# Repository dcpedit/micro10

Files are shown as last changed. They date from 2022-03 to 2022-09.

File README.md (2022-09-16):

# µ10 Keyboard

µ10_keyboard

Here you will find all the source files I used to build my µ10 (aka Micro10) keyboard.  Below is a list of features:

* 10u wide QAZ-ish layout
* Supports a 10u spacebar
* Designed to be wireless (via nice!nano + ZMK)
* Optional daughterboard for OLED and rotary encoder
* PCB uses Kailh hot swap sockets
* PCB supports a 1.25u modifier on each end if a split spacebar (2.25u + 2.75u) setup or 6.25u spacebar is utilized.  This will require modifications to the case design (mainly to add blockers).

[Keyboard Layout Editor (KLE)](http://www.keyboard-layout-editor.com/#/gists/2a9c0bfd3bc5586766325f682a7adc31)

keymap_legend
keymap_current

# ZMK Firmware

See my fork of ZMK under the `dcpedit` branch:
https://github.com/dcpedit/zmk/tree/dcpedit

The relevant files are in the `micro10` folder under shields:
https://github.com/dcpedit/zmk/tree/dcpedit/app/boards/shields/micro10

```
git clone -b dcpedit https://github.com/dcpedit/zmk.git
```

## Build
Follow the [ZMK environment setup](https://zmk.dev/docs/development/setup).  I highly recommend using VS Code & Docker.
```
cd app
west build -b nice_nano_v2 -- -DSHIELD=micro10
```
Binary will be located here.  Copy it into your nice!nano:
```
app/build/zephyr/zmk.uf2
```

# Image Gallery
https://imgur.com/a/AuKd2NT

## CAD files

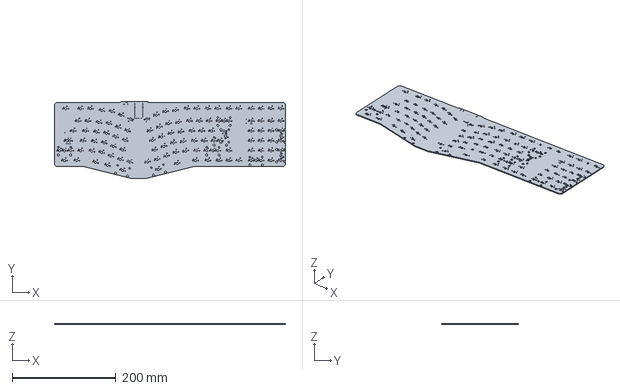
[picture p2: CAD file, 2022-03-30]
pcb/micro10.step
445.0 x 148.2 x 1.60 mm

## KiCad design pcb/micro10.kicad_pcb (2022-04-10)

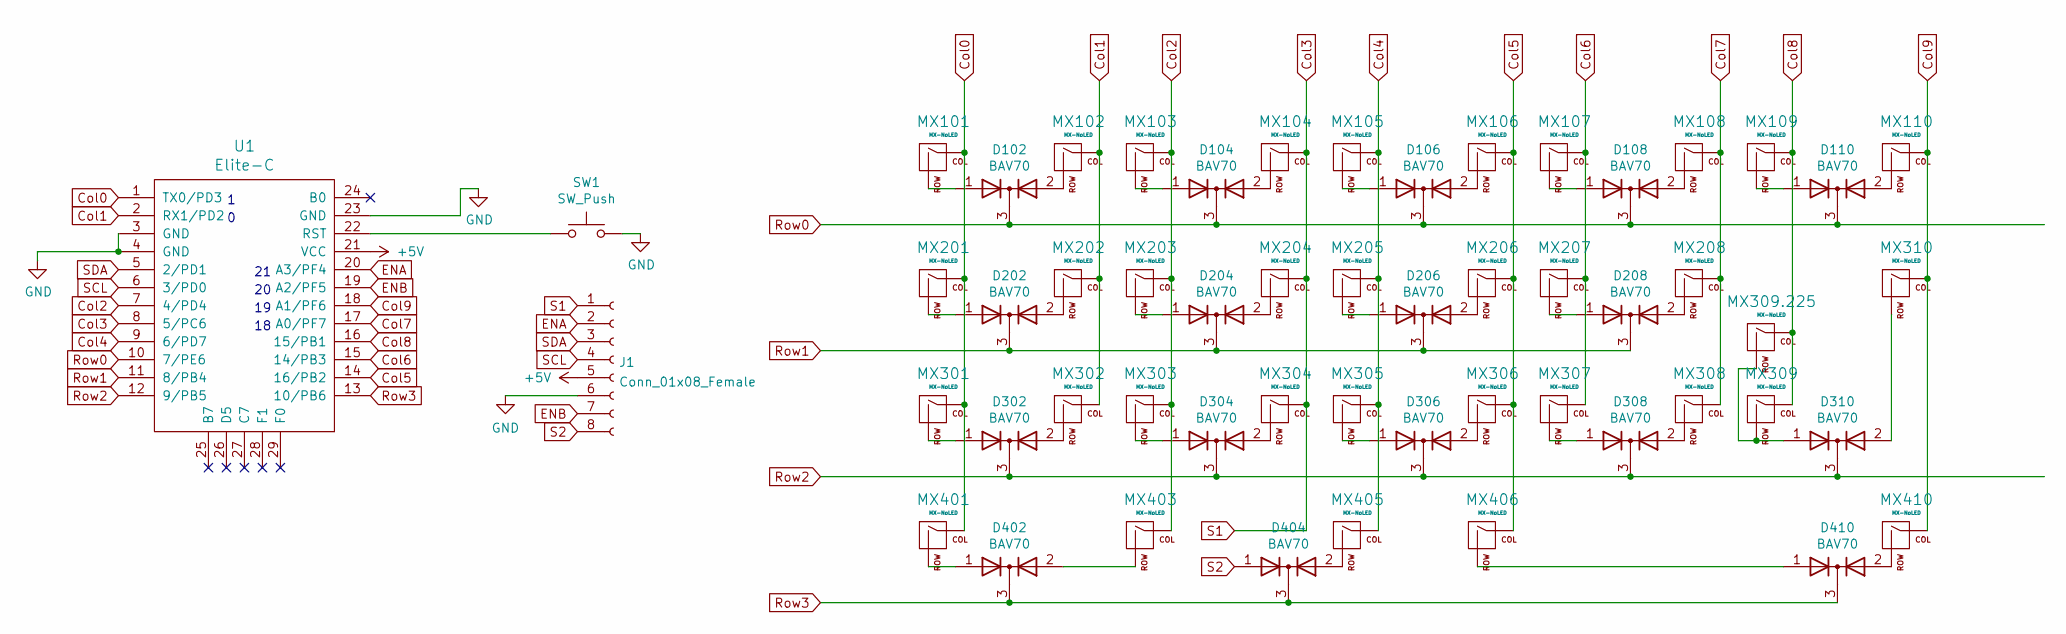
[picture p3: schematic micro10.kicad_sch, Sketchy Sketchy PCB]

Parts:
D102, D104, D106, D108, D110, D202, D204, D206, D208, D302, D304, D306, D308, D310, D402, D404, D410: BAV70; SOT-23_Handsoldering
J1: Conn_01x08_Female
MX101, MX102, MX103, MX104, MX105, MX106, MX107, MX108, MX109, MX110, MX202, MX203, MX204, MX205, MX206, MX207, MX208, MX302, MX303, MX304, MX305, MX306, MX307, MX308, MX309, MX309.225, MX310, MX403, MX405, MX406, MX410: MX-NoLED; MXOnly-1U-Hotswap
MX201: MX-NoLED; MXOnly-1.5U-Hotswap
MX301: MX-NoLED; MXOnly-1.75U-Hotswap
MX401: MX-NoLED; MXOnly-2.25U-Hotswap
SW1: SW_Push; SW_Tactile_SPST_Angled_MJTP1117
U1: Elite-C

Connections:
+5V: J1.5, U1.21 (VCC)
Col0: MX101.1 (COL), MX201.1 (COL), MX301.1 (COL), MX401.1 (COL), U1.1 (TX0/PD3)
Col1: MX102.1 (COL), MX202.1 (COL), MX302.1 (COL), U1.2 (RX1/PD2)
Col2: MX103.1 (COL), MX203.1 (COL), MX303.1 (COL), MX403.1 (COL), U1.7 (4/PD4)
Col3: J1.1, MX104.1 (COL), MX204.1 (COL), MX304.1 (COL), U1.8 (5/PC6)
Col4: MX105.1 (COL), MX205.1 (COL), MX305.1 (COL), MX405.1 (COL), U1.9 (6/PD7)
Col5: MX106.1 (COL), MX206.1 (COL), MX306.1 (COL), MX406.1 (COL), U1.14 (16/PB2)
Col6: MX107.1 (COL), MX207.1 (COL), MX307.1 (COL), U1.15 (14/PB3)
Col7: MX108.1 (COL), MX208.1 (COL), MX308.1 (COL), U1.17 (A0/PF7)
Col8: MX109.1 (COL), MX309.1 (COL), MX309.225.1 (COL), U1.16 (15/PB1)
Col9: MX110.1 (COL), MX310.1 (COL), MX410.1 (COL), U1.18 (A1/PF6)
ENA: J1.2, U1.20 (A3/PF4)
ENB: J1.7, U1.19 (A2/PF5)
GND: J1.6, SW1.2, U1.3 (GND), U1.4 (GND), U1.23 (GND)
unnamed: D102.1 (A), MX101.2 (ROW)
unnamed: D102.2 (A), MX102.2 (ROW)
unnamed: D104.1 (A), MX103.2 (ROW)
unnamed: D104.2 (A), MX104.2 (ROW)
unnamed: D106.1 (A), MX105.2 (ROW)
unnamed: D106.2 (A), MX106.2 (ROW)
unnamed: D108.1 (A), MX107.2 (ROW)
unnamed: D108.2 (A), MX108.2 (ROW)
unnamed: D110.1 (A), MX109.2 (ROW)
unnamed: D110.2 (A), MX110.2 (ROW)
unnamed: D202.1 (A), MX201.2 (ROW)
unnamed: D202.2 (A), MX202.2 (ROW)
unnamed: D204.1 (A), MX203.2 (ROW)
unnamed: D204.2 (A), MX204.2 (ROW)
unnamed: D206.1 (A), MX205.2 (ROW)
unnamed: D206.2 (A), MX206.2 (ROW)
unnamed: D208.1 (A), MX207.2 (ROW)
unnamed: D208.2 (A), MX208.2 (ROW)
unnamed: D302.1 (A), MX301.2 (ROW)
unnamed: D302.2 (A), MX302.2 (ROW)
unnamed: D304.1 (A), MX303.2 (ROW)
unnamed: D304.2 (A), MX304.2 (ROW)
unnamed: D306.1 (A), MX305.2 (ROW)
unnamed: D306.2 (A), MX306.2 (ROW)
unnamed: D308.1 (A), MX307.2 (ROW)
unnamed: D308.2 (A), MX308.2 (ROW)
unnamed: D310.1 (A), MX309.2 (ROW), MX309.225.2 (ROW)
unnamed: D310.2 (A), MX310.2 (ROW)
unnamed: D402.1 (A), MX401.2 (ROW)
unnamed: D402.2 (A), MX403.2 (ROW)
unnamed: D404.2 (A), MX405.2 (ROW)
unnamed: D410.1 (A), MX406.2 (ROW)
unnamed: D410.2 (A), MX410.2 (ROW)
unnamed: SW1.1, U1.22 (RST)
Row0: D102.3 (K), D104.3 (K), D106.3 (K), D108.3 (K), D110.3 (K), U1.10 (7/PE6)
Row1: D202.3 (K), D204.3 (K), D206.3 (K), D208.3 (K), U1.11 (8/PB4)
Row2: D302.3 (K), D304.3 (K), D306.3 (K), D308.3 (K), D310.3 (K), U1.12 (9/PB5)
Row3: D402.3 (K), D404.3 (K), D410.3 (K), U1.13 (10/PB6)
S2: D404.1 (A), J1.8
SCL: J1.4, U1.6 (3/PD0)
SDA: J1.3, U1.5 (2/PD1)

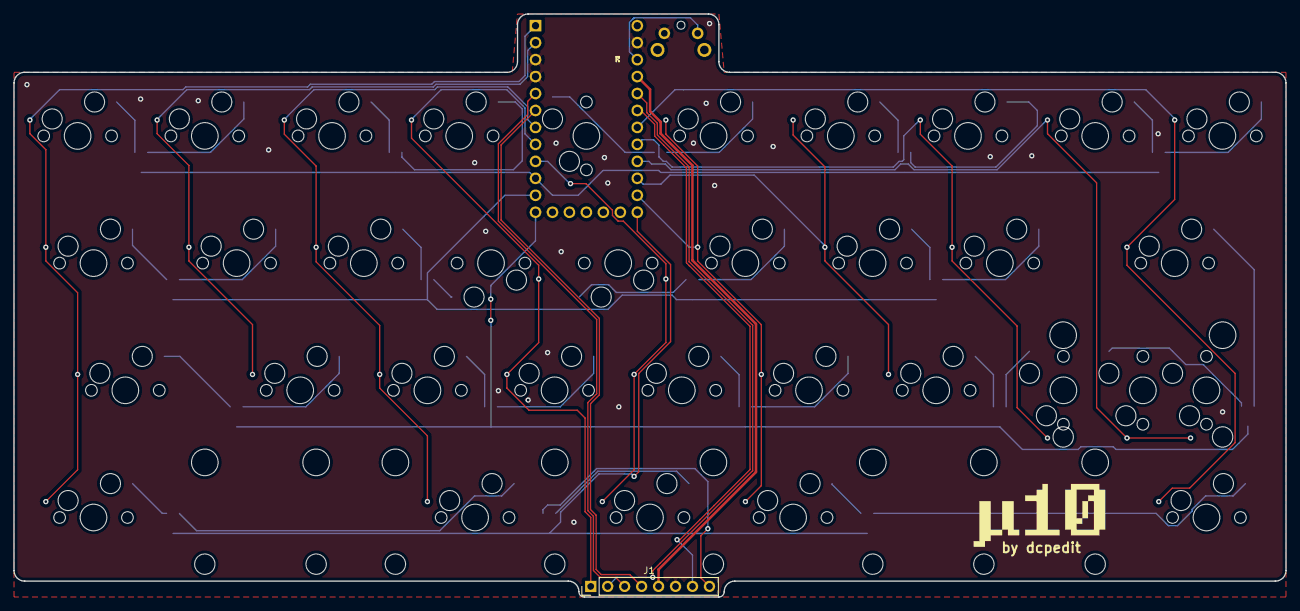
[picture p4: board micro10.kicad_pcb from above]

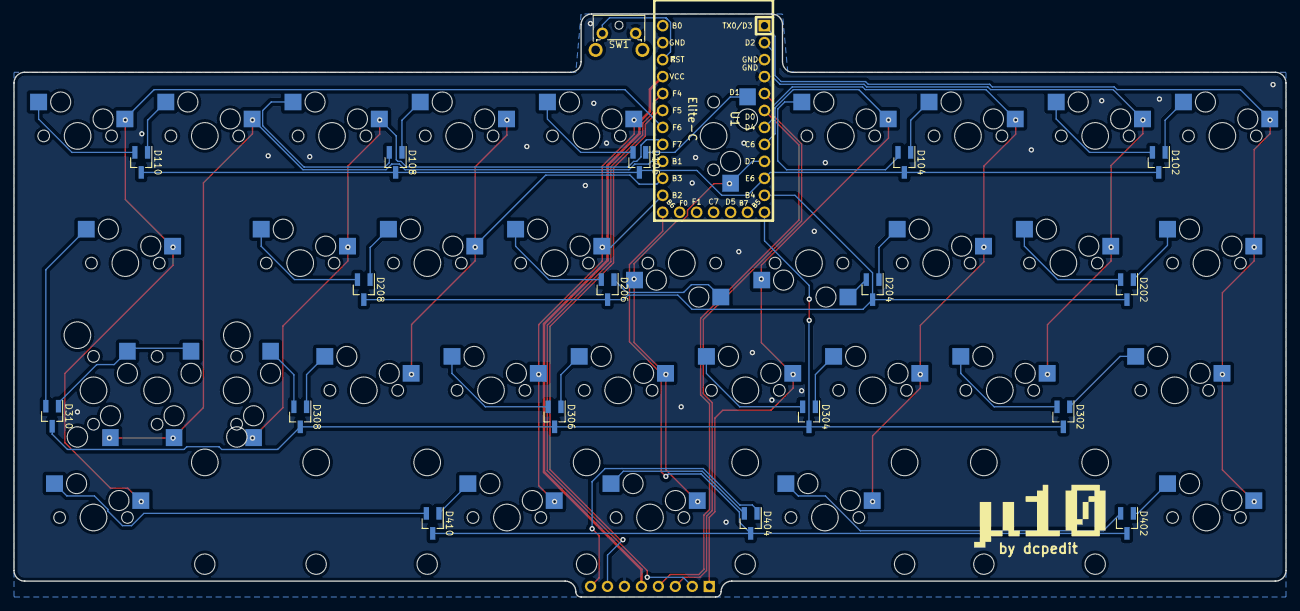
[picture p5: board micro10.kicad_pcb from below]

Board: 2 copper layers, 190.5 x 87.3 mm, 54 parts (18 on the bottom side), 55 nets.

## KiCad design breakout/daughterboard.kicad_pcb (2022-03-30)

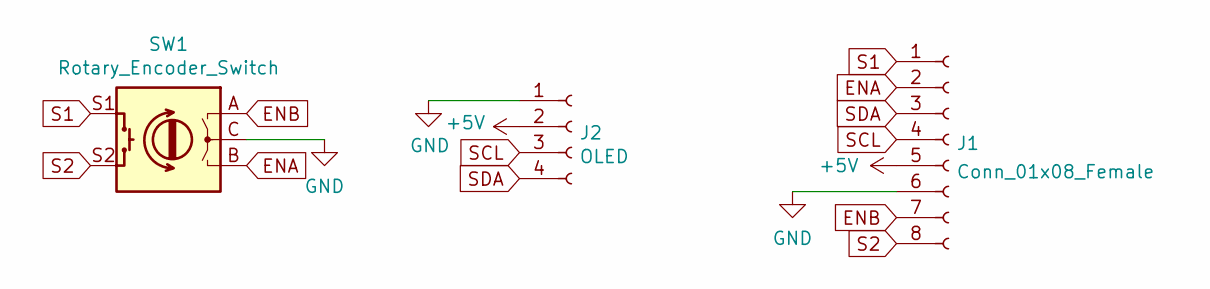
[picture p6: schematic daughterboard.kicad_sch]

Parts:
J1: Conn_01x08_Female; PinHeader_1x08_P2.54mm_Vertical
J2: OLED; SSD1306_OLED
SW1: Rotary_Encoder_Switch; RotaryEncoder_Alps_EC11E-Switch_Vertical_H20mm

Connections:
+5V: J1.5, J2.2
ENA: J1.2, SW1.B
ENB: J1.7, SW1.A
GND: J1.6, J2.1, SW1.C
S1: J1.1, SW1.S1
S2: J1.8, SW1.S2
SCL: J1.4, J2.3
SDA: J1.3, J2.4

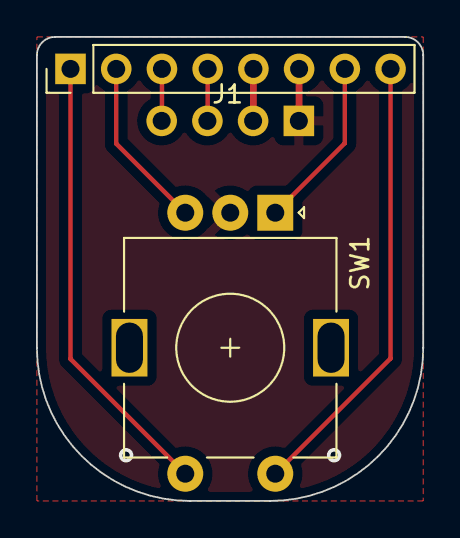
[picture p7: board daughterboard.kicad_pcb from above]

Board: 2 copper layers, 21.5 x 25.8 mm, 3 parts (0 on the bottom side), 8 nets.

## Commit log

2022-04-10 Case files
    [micro10.kicad_pcb, micro10.kicad_sch, plate.kicad_pcb]
2022-05-14 Add readme
    [plate.kicad_pcb]
2022-05-14 Remove outdated gerbers
    [micro10-B_Cu.gbl, micro10-B_Mask.gbs, micro10-B_Paste.gbp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]
